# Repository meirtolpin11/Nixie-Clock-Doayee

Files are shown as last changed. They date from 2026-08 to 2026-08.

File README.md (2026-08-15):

# Nixie Clock Driver (Doayee IN-12B)

A 6-digit IN-12B Nixie tube display and driver board designed in KiCad.

Schematic Preview

---

## Overview

This project is a modular Nixie tube driver board tailored for Russian **IN-12B** cold-cathode neon display tubes. It utilizes the **HV5122PG** high-voltage 32-channel shift register IC to drive tube cathodes with minimal microcontroller I/O pins, paired with individually driven RGB backlights underneath each tube.

### Key Features
* **6x IN-12B Nixie Tube Sockets**: DSUB-style footprint mounting with decimal point support.
* **Microchip/Supertex HV5122PG High-Voltage Driver**: 32 high-voltage open-drain outputs with internal shift register and latch.
* **RGB Tube Backlighting**: Dedicated Cree PLCC4 / SMD RGB LEDs for under-glow effects.
* **Integrated Logic**: 74LVC1G79 D-type flip-flop for high-speed clock/data synchronization.
* **Self-Contained Library Management**: All custom symbols, footprints, and 3D models are bundled in the repository and mapped via relative project variables (`${KIPRJMOD}`).

---

## Repository Structure

```
├── Nixie.kicad_pro              # KiCad project file
├── Nixie.kicad_sch              # Main schematic
├── Nixie.kicad_pcb              # PCB layout
├── sym-lib-table                # Project symbol library table (portable ${KIPRJMOD})
├── fp-lib-table                 # Project footprint library table (portable ${KIPRJMOD})
├── libs/                        # Bundled component libraries
│   ├── symbols/                 # Symbol libraries (.kicad_sym)
│   │   ├── HV5122_Doayee.kicad_sym
│   │   ├── HV5122PG-G.kicad_sym
│   │   ├── 74LVC1G79GW-Q100H.kicad_sym
│   │   ├── nixies-us.kicad_sym
│   │   ├── mynixies.kicad_sym
│   │   ├── nixiemisc.kicad_sym
│   │   └── CustomComponents.kicad_sym
│   ├── footprints/              # Footprint libraries (.pretty folders)
│   │   ├── HV5122PG-G.pretty/
│   │   ├── 74LVC1G79GW.pretty/
│   │   ├── nixies-us.pretty/
│   │   ├── mynixies.pretty/
│   │   ├── nixiemisc.pretty/
│   │   └── CustomComponents.pretty/
│   └── 3dmodels/                # 3D models (.wrl / .step)
│       └── IN-12B.wrl, box_header_*.wrl
├── datasheets/                  # Component datasheets (IN-12B, HV5122, etc.)
├── production/                  # Manufacturing outputs
│   └── gerbers/                 # Gerbers and drill files
├── docs/                        # Exported documentation
│   ├── schematic.pdf            # Schematic in PDF format
│   └── pcb_top.svg              # Top-layer SVG rendering
└── archive/                     # Historical KiCad 4/5 files
    └── legacy_kicad4/
```

---

## How to Open in KiCad

1. Clone this repository:
   ```bash
   git clone git@github.com:meirtolpin11/Nixie-Clock-Doayee.git
   ```
2. Open **KiCad** (version 7, 8, 9, or 10).
3. Select **File -> Open Project...** and select `Nixie.kicad_pro`.
4. All symbols and footprints are pre-configured to resolve automatically using `${KIPRJMOD}`—no manual library configuration is needed.

---

## Documentation & Exports

* **Schematic PDF**: [docs/schematic.pdf](docs/schematic.pdf)
* **Gerber Files**: [production/gerbers/](production/gerbers/)
* **Datasheets**: [datasheets/](datasheets/)

---

## License

Hardware design and files are provided for personal and open-source hobbyist use.

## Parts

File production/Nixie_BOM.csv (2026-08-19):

Refs | Value | Footprint | Qty | DNP
C6 | 100nF | Capacitor_THT:C_Disc_D4.7mm_W2.5mm_P5.00mm | 1
C7 | 100nF | Capacitor_THT:C_Disc_D4.7mm_W2.5mm_P5.00mm | 1
C8 | 10nF | Capacitor_THT:C_Disc_D4.7mm_W2.5mm_P5.00mm | 1
C9 | 10nF | Capacitor_THT:C_Disc_D4.7mm_W2.5mm_P5.00mm | 1
D1 | Led_RGB_CA | LED_SMD:LED_Cree-PLCC4_5x5mm_CW | 1
D2 | Led_RGB_CA | LED_SMD:LED_Cree-PLCC4_5x5mm_CW | 1
D3 | Led_RGB_CA | LED_SMD:LED_Cree-PLCC4_5x5mm_CW | 1
D4 | Led_RGB_CA | LED_SMD:LED_Cree-PLCC4_5x5mm_CW | 1
D5 | LED | LED_THT:LED_D3.0mm | 1
D6 | Led_RGB_CA | LED_SMD:LED_Cree-PLCC4_5x5mm_CW | 1
D7 | Led_RGB_CA | LED_SMD:LED_Cree-PLCC4_5x5mm_CW | 1
J1 | Led output | Connector_PinHeader_2.54mm:PinHeader_1x18_P2.54mm_Vertical | 1
J2 | Led Input | Connector_PinHeader_2.54mm:PinHeader_1x18_P2.54mm_Vertical | 1
J3 | Conn_01x03 | Connector_PinHeader_2.54mm:PinHeader_1x03_P2.54mm_Vertical | 1
JP1 | M10LOCK | Connector_PinHeader_2.54mm:PinHeader_1x07_P2.54mm_Vertical | 1
N1 | IN-12B | nixies-us:nixies-us-IN-12-DSUB-NOHOLE | 1
N2 | IN-12B | nixies-us:nixies-us-IN-12-DSUB-NOHOLE | 1
N3 | IN-12B | nixies-us:nixies-us-IN-12-DSUB-NOHOLE | 1
N4 | IN-12B | nixies-us:nixies-us-IN-12-DSUB-NOHOLE | 1
N5 | IN-12B | nixies-us:nixies-us-IN-12-DSUB-NOHOLE | 1
N6 | IN-12B | nixies-us:nixies-us-IN-12-DSUB-NOHOLE | 1
Q1 | Q_NMOS_GSD | Package_TO_SOT_SMD:SOT-23 | 1
R1 | 100R | Resistor_THT:R_Axial_DIN0207_L6.3mm_D2.5mm_P7.62mm_Horizontal | 1
R2 | 120R | Resistor_THT:R_Axial_DIN0207_L6.3mm_D2.5mm_P7.62mm_Horizontal | 1
R3 | 120R | Resistor_THT:R_Axial_DIN0207_L6.3mm_D2.5mm_P7.62mm_Horizontal | 1
R4 | 1K5 | Resistor_THT:R_Axial_DIN0207_L6.3mm_D2.5mm_P7.62mm_Horizontal | 1
R5 | 1K5 | Resistor_THT:R_Axial_DIN0207_L6.3mm_D2.5mm_P7.62mm_Horizontal | 1
R6 | 1K5 | Resistor_THT:R_Axial_DIN0207_L6.3mm_D2.5mm_P7.62mm_Horizontal | 1
R7 | 1K5 | Resistor_THT:R_Axial_DIN0207_L6.3mm_D2.5mm_P7.62mm_Horizontal | 1
R8 | 1K5 | Resistor_THT:R_Axial_DIN0207_L6.3mm_D2.5mm_P7.62mm_Horizontal | 1
R9 | 1K5 | Resistor_THT:R_Axial_DIN0207_L6.3mm_D2.5mm_P7.62mm_Horizontal | 1
R10 | 100R | Resistor_THT:R_Axial_DIN0207_L6.3mm_D2.5mm_P7.62mm_Horizontal | 1
R11 | 120R | Resistor_THT:R_Axial_DIN0207_L6.3mm_D2.5mm_P7.62mm_Horizontal | 1
R12 | 120R | Resistor_THT:R_Axial_DIN0207_L6.3mm_D2.5mm_P7.62mm_Horizontal | 1
R13 | 100R | Resistor_THT:R_Axial_DIN0207_L6.3mm_D2.5mm_P7.62mm_Horizontal | 1
R14 | 120R | Resistor_THT:R_Axial_DIN0207_L6.3mm_D2.5mm_P7.62mm_Horizontal | 1
R15 | 120R | Resistor_THT:R_Axial_DIN0207_L6.3mm_D2.5mm_P7.62mm_Horizontal | 1
R16 | 100R | Resistor_THT:R_Axial_DIN0207_L6.3mm_D2.5mm_P7.62mm_Horizontal | 1
R17 | 120R | Resistor_THT:R_Axial_DIN0207_L6.3mm_D2.5mm_P7.62mm_Horizontal | 1
R18 | 120R | Resistor_THT:R_Axial_DIN0207_L6.3mm_D2.5mm_P7.62mm_Horizontal | 1
R19 | 120R | Resistor_THT:R_Axial_DIN0207_L6.3mm_D2.5mm_P7.62mm_Horizontal | 1
R20 | 100R | Resistor_THT:R_Axial_DIN0207_L6.3mm_D2.5mm_P7.62mm_Horizontal | 1
R21 | 120R | Resistor_THT:R_Axial_DIN0207_L6.3mm_D2.5mm_P7.62mm_Horizontal | 1
R22 | 120R | Resistor_THT:R_Axial_DIN0207_L6.3mm_D2.5mm_P7.62mm_Horizontal | 1
R23 | 100R | Resistor_THT:R_Axial_DIN0207_L6.3mm_D2.5mm_P7.62mm_Horizontal | 1
R24 | 120R | Resistor_THT:R_Axial_DIN0207_L6.3mm_D2.5mm_P7.62mm_Horizontal | 1
R25 | 120R | Resistor_THT:R_Axial_DIN0207_L6.3mm_D2.5mm_P7.62mm_Horizontal | 1
R26 | 10K | Resistor_THT:R_Axial_DIN0207_L6.3mm_D2.5mm_P7.62mm_Horizontal | 1
R27 | 10K | Resistor_THT:R_Axial_DIN0207_L6.3mm_D2.5mm_P7.62mm_Horizontal | 1
U1 | 74LVC1G79 | Package_TO_SOT_SMD:SOT-23-5_HandSoldering | 1
U2 | HV5122 | HV5122PG-G:QFP80P1390X1390X235-44N | 1
U3 | HV5122 | HV5122PG-G:QFP80P1390X1390X235-44N | 1

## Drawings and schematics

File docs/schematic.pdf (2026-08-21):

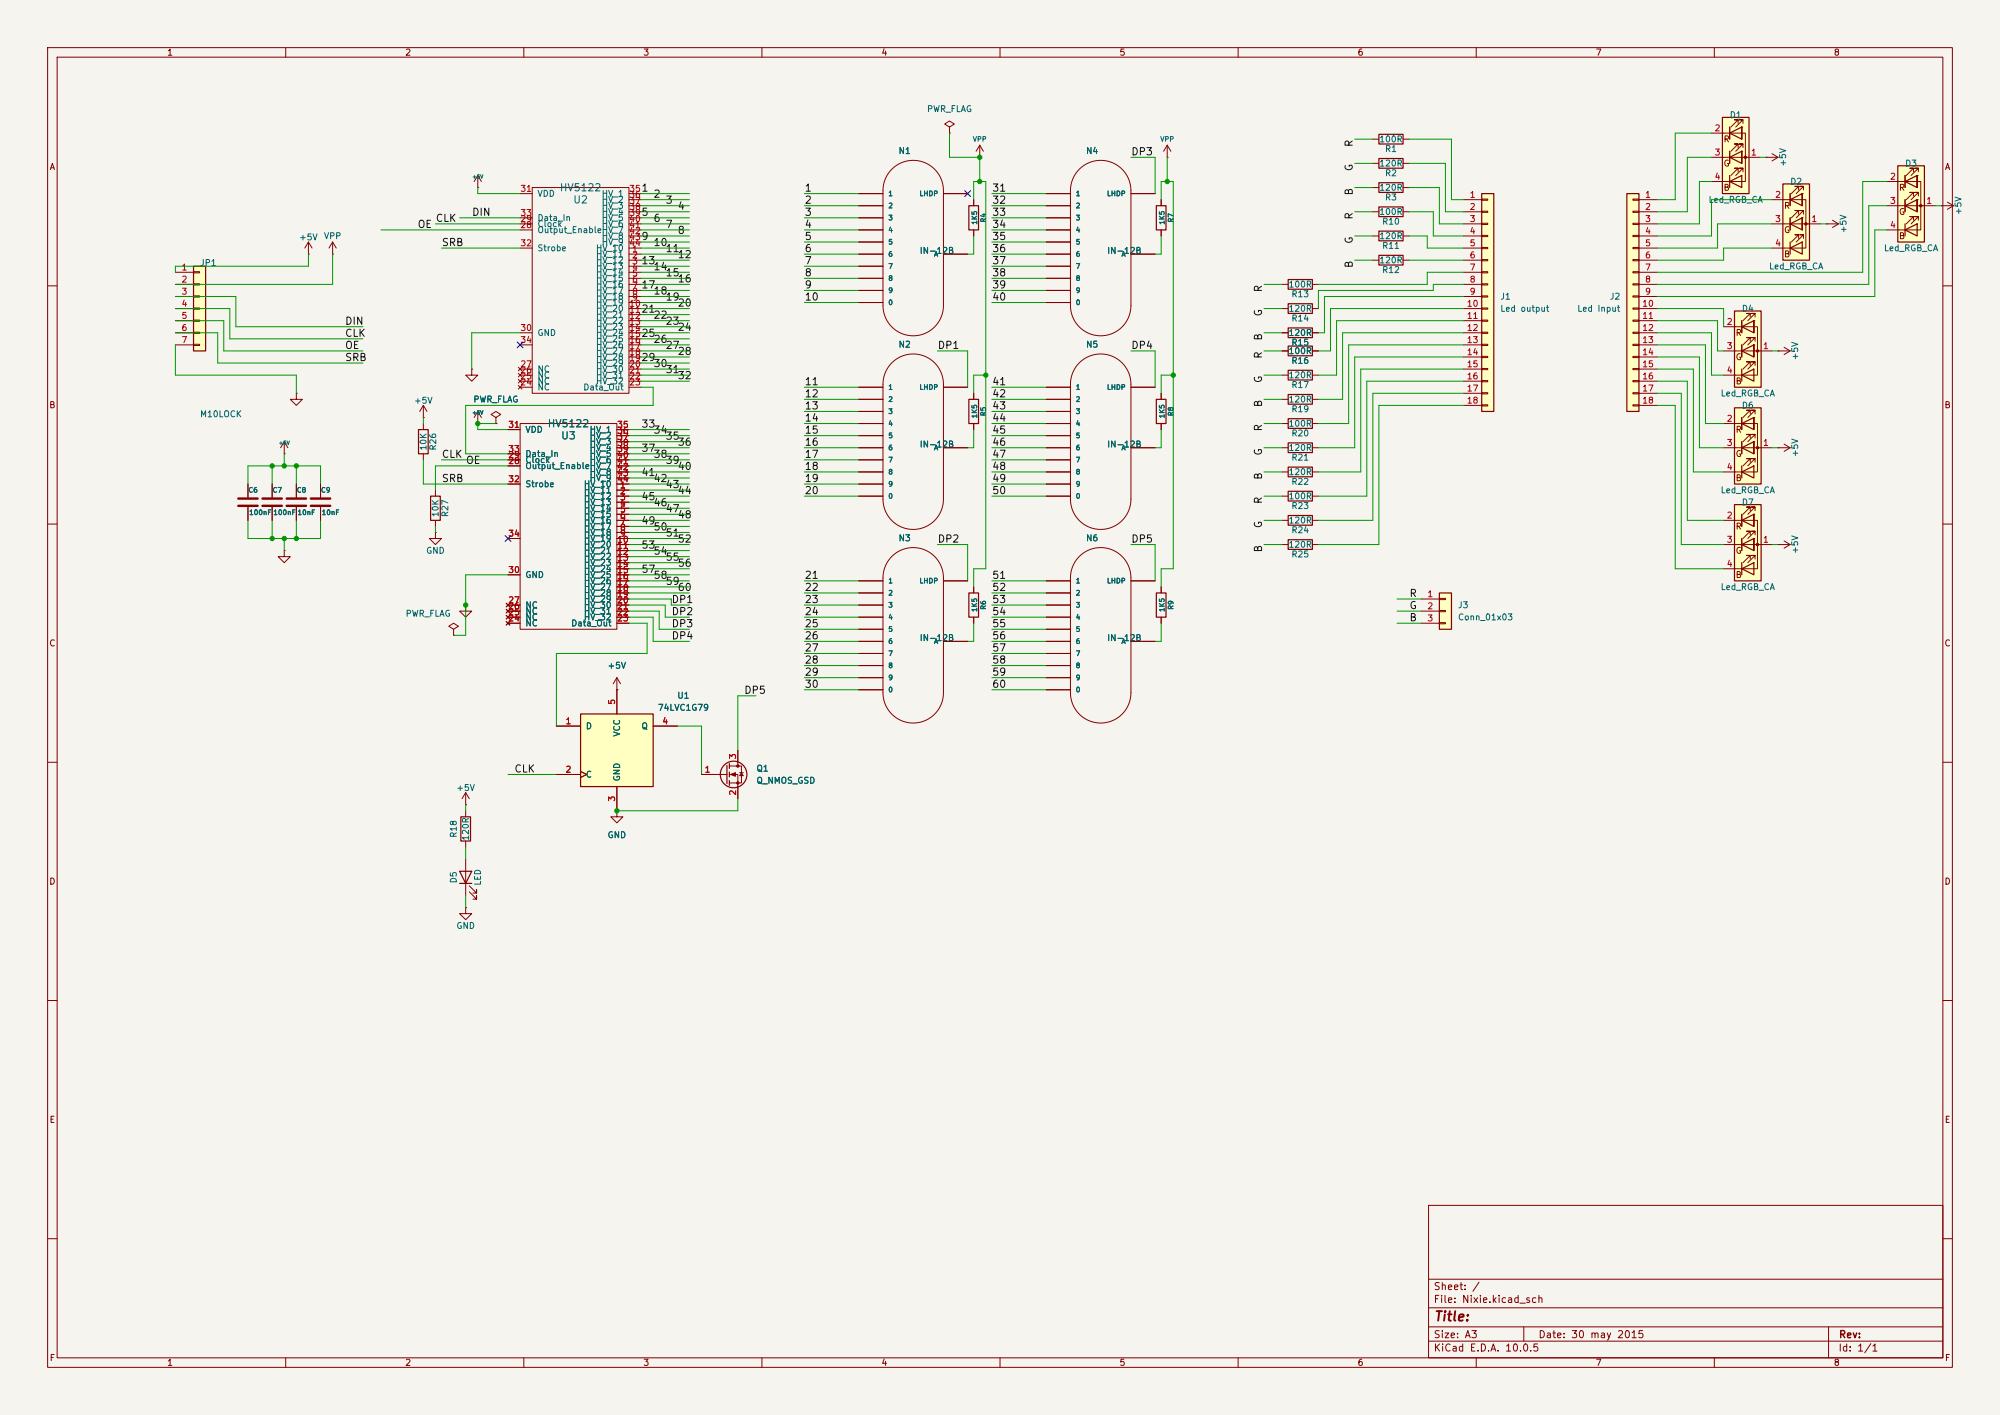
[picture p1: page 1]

Size: A3 | Rev: | F Date: 30 may 2015
KiCad E.D.A. 10.0.5 | Id: 1/1

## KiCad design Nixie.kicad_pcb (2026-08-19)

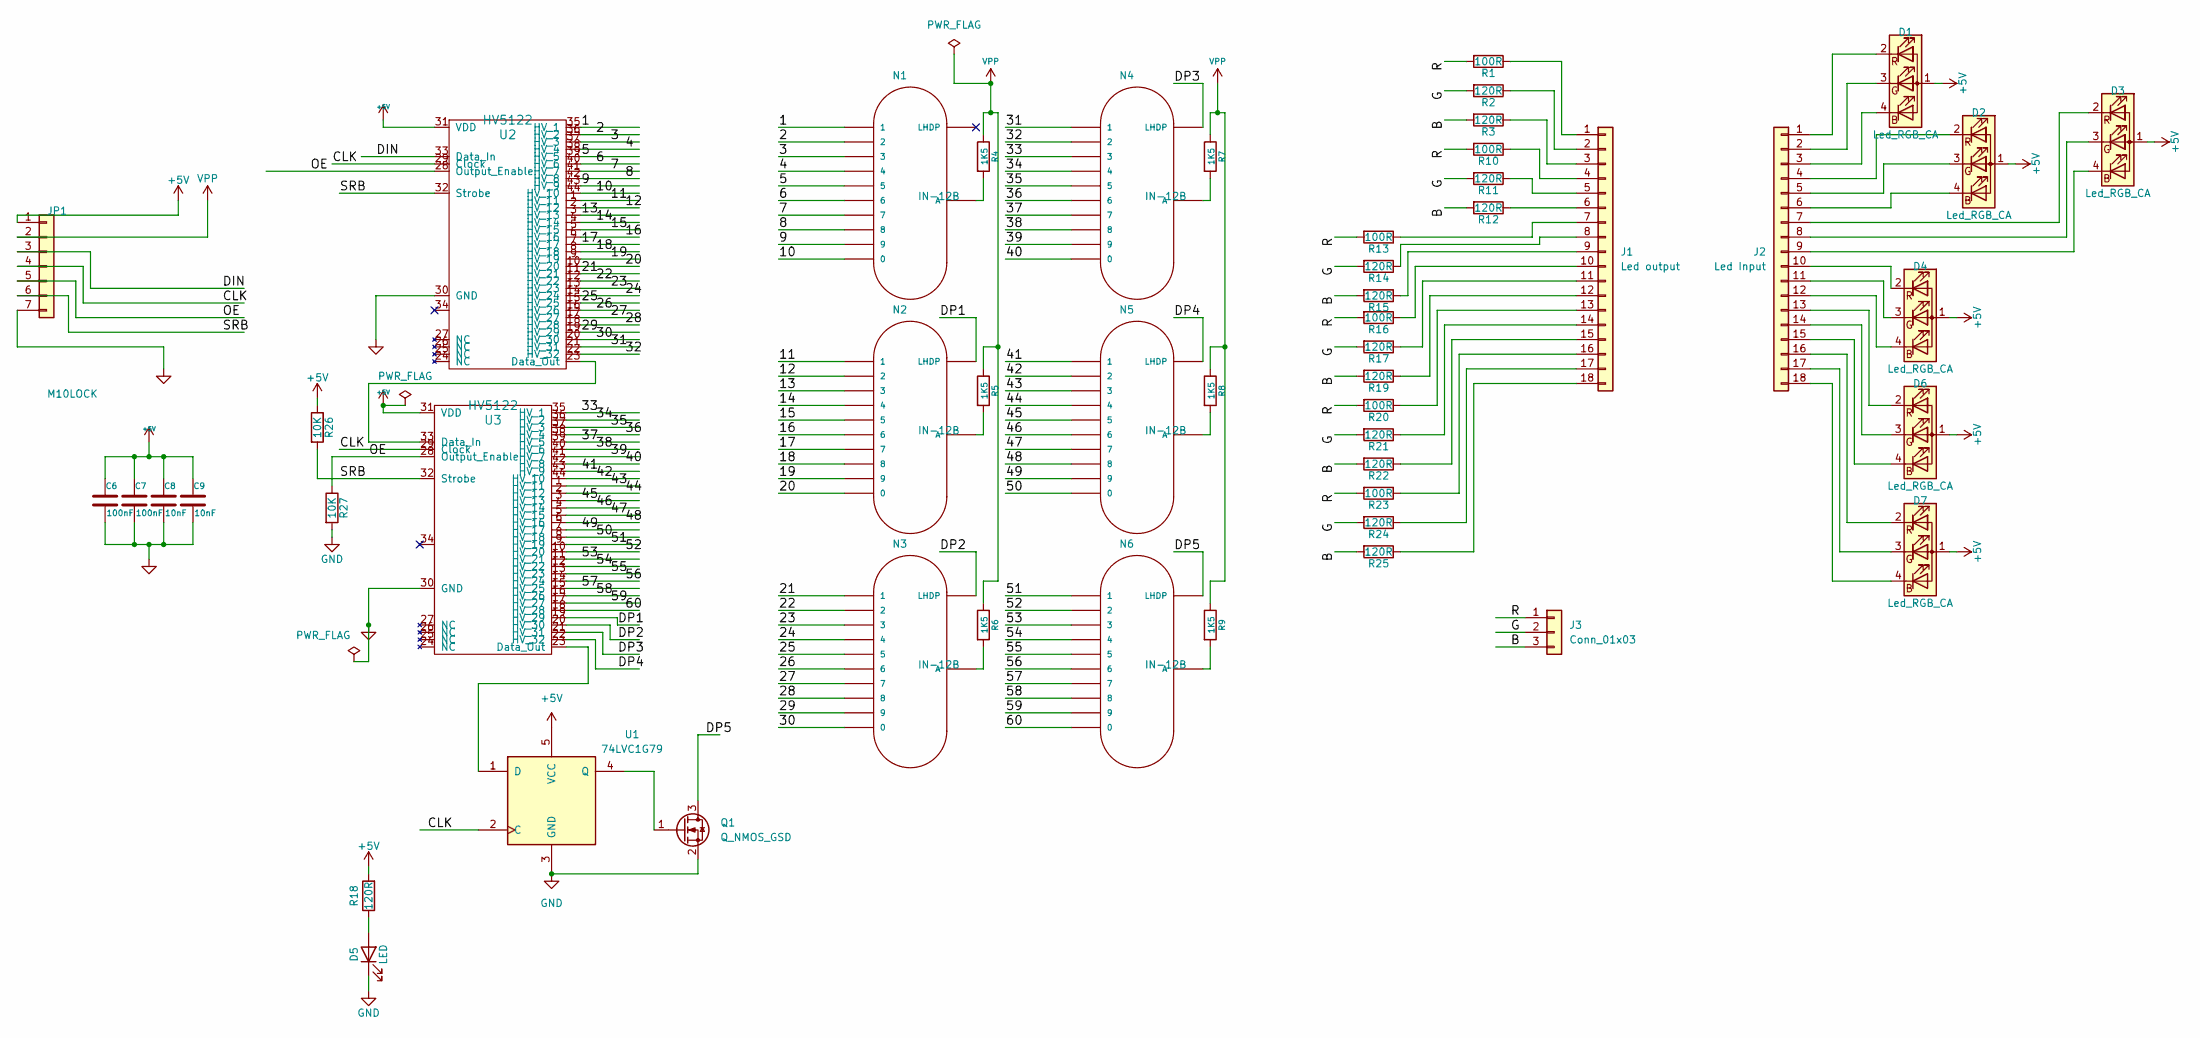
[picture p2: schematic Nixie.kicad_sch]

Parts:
C6, C7: 100nF; C_Disc_D3.0mm_W2.0mm_P2.50mm
C8, C9: 10nF; C_Disc_D3.0mm_W2.0mm_P2.50mm
D1, D2, D3, D4, D6, D7: Led_RGB_CA; LED_Cree-PLCC4_5x5mm_CW
D5: LED; LED_D3.0mm
J1: Led output; PinHeader_1x20_P1.00mm_Vertical
J2: Led Input; PinHeader_1x20_P1.00mm_Vertical
J3: Conn_01x03; PinHeader_1x03_P1.00mm_Vertical
JP1: M10LOCK; PinHeader_1x10_P1.00mm_Vertical
N1, N2, N3, N4, N5, N6: IN-12B; nixies-us-IN-12-DSUB-NOHOLE
Q1: Q_NMOS_GSD; SOT-23
R1, R10, R13, R16, R20, R23: 100R; R_Axial_DIN0207_L6.3mm_D2.5mm_P7.62mm_Horizontal
R2, R3, R11, R12, R14, R15, R17, R18, R19, R21, R22, R24, R25: 120R; R_Axial_DIN0207_L6.3mm_D2.5mm_P7.62mm_Horizontal
R4, R5, R6, R7, R8, R9: 1K5; R_Axial_DIN0207_L6.3mm_D2.5mm_P7.62mm_Horizontal
R26, R27: 10K; R_Axial_DIN0207_L6.3mm_D2.5mm_P7.62mm_Horizontal
U1: 74LVC1G79; SOT-23-5_HandSoldering
U2, U3: HV5122; QFP80P1390X1390X235-44N

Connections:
+5V: C6.1, C7.1, C8.1, C9.1, D1.1 (A), D2.1 (A), D3.1 (A), D4.1 (A), D6.1 (A), D7.1 (A), JP1.1, R18.2, R26.1, U1.5 (VCC), U2.31 (VDD), U3.31 (VDD)
/1: N1.1, U2.35 (HV_1)
/2: N1.2, U2.36 (HV_2)
/3: N1.3, U2.37 (HV_3)
/4: N1.4, U2.38 (HV_4)
/5: N1.5, U2.39 (HV_5)
/6: N1.6, U2.40 (HV_6)
/7: N1.7, U2.41 (HV_7)
/8: N1.8, U2.42 (HV_8)
/9: N1.9, U2.43 (HV_9)
/10: N1.0, U2.44 (HV_10)
/11: N2.1, U2.1 (HV_11)
/12: N2.2, U2.2 (HV_12)
/13: N2.3, U2.3 (HV_13)
/14: N2.4, U2.4 (HV_14)
/15: N2.5, U2.5 (HV_15)
/16: N2.6, U2.6 (HV_16)
/17: N2.7, U2.7 (HV_17)
/18: N2.8, U2.8 (HV_18)
/19: N2.9, U2.9 (HV_19)
/20: N2.0, U2.10 (HV_20)
/21: N3.1, U2.11 (HV_21)
/22: N3.2, U2.12 (HV_22)
/23: N3.3, U2.13 (HV_23)
/24: N3.4, U2.14 (HV_24)
/25: N3.5, U2.15 (HV_25)
/26: N3.6, U2.16 (HV_26)
/27: N3.7, U2.17 (HV_27)
/28: N3.8, U2.18 (HV_28)
/29: N3.9, U2.19 (HV_29)
/30: N3.0, U2.20 (HV_30)
/31: N4.1, U2.21 (HV_31)
/32: N4.2, U2.22 (HV_32)
/33: N4.3, U3.35 (HV_1)
/34: N4.4, U3.36 (HV_2)
/35: N4.5, U3.37 (HV_3)
/36: N4.6, U3.38 (HV_4)
/37: N4.7, U3.39 (HV_5)
/38: N4.8, U3.40 (HV_6)
/39: N4.9, U3.41 (HV_7)
/40: N4.0, U3.42 (HV_8)
/41: N5.1, U3.43 (HV_9)
/42: N5.2, U3.44 (HV_10)
/43: N5.3, U3.1 (HV_11)
/44: N5.4, U3.2 (HV_12)
/45: N5.5, U3.3 (HV_13)
/46: N5.6, U3.4 (HV_14)
/47: N5.7, U3.5 (HV_15)
/48: N5.8, U3.6 (HV_16)
/49: N5.9, U3.7 (HV_17)
/50: N5.0, U3.8 (HV_18)
/51: N6.1, U3.9 (HV_19)
/52: N6.2, U3.10 (HV_20)
/53: N6.3, U3.11 (HV_21)
/54: N6.4, U3.12 (HV_22)
/55: N6.5, U3.13 (HV_23)
/56: N6.6, U3.14 (HV_24)
/57: N6.7, U3.15 (HV_25)
/58: N6.8, U3.16 (HV_26)
/59: N6.9, U3.17 (HV_27)
/60: N6.0, U3.18 (HV_28)
/B: J3.3, R3.2, R12.2, R15.2, R19.2, R22.2, R25.2
/CLK: JP1.4, U1.2 (C), U2.29 (Clock), U3.29 (Clock)
/DIN: JP1.3, U2.33 (Data_In)
/DP1: N2.LHDP, U3.19 (HV_29)
/DP2: N3.LHDP, U3.20 (HV_30)
/DP3: N4.LHDP, U3.21 (HV_31)
/DP4: N5.LHDP, U3.22 (HV_32)
/DP5: N6.LHDP, Q1.3 (D)
/G: J3.2, R2.2, R11.2, R14.2, R17.2, R21.2, R24.2
/OE: JP1.5, R27.1, U2.28 (Output_Enable), U3.28 (Output_Enable)
/R: J3.1, R1.2, R10.2, R13.2, R16.2, R20.2, R23.2
/SRB: JP1.6, R26.2, U2.32 (Strobe), U3.32 (Strobe)
GND: C6.2, C7.2, C8.2, C9.2, D5.1 (K), JP1.7, Q1.2 (S), R27.2, U1.3 (GND), U2.30 (GND), U3.30 (GND)
unnamed: D1.4 (BK), J2.3
unnamed: D1.3 (GK), J2.2
unnamed: D1.2 (RK), J2.1
unnamed: D2.4 (BK), J2.6
unnamed: D2.3 (GK), J2.5
unnamed: D2.2 (RK), J2.4
unnamed: D3.4 (BK), J2.9
unnamed: D3.3 (GK), J2.8
unnamed: D3.2 (RK), J2.7
unnamed: D4.4 (BK), J2.12
unnamed: D4.3 (GK), J2.11
unnamed: D4.2 (RK), J2.10
unnamed: D5.2 (A), R18.1
unnamed: D6.4 (BK), J2.15
unnamed: D6.3 (GK), J2.14
unnamed: D6.2 (RK), J2.13
unnamed: D7.4 (BK), J2.18
unnamed: D7.3 (GK), J2.17
unnamed: D7.2 (RK), J2.16
unnamed: J1.1, R1.1
unnamed: J1.2, R2.1
unnamed: J1.3, R3.1
unnamed: J1.4, R10.1
unnamed: J1.5, R11.1
unnamed: J1.6, R12.1
unnamed: J1.7, R13.1
unnamed: J1.8, R14.1
unnamed: J1.9, R15.1
unnamed: J1.10, R16.1
unnamed: J1.11, R17.1
unnamed: J1.12, R19.1
unnamed: J1.13, R20.1
unnamed: J1.14, R21.1
unnamed: J1.15, R22.1
unnamed: J1.16, R23.1
unnamed: J1.17, R24.1
unnamed: J1.18, R25.1
unnamed: N1.A, R4.2
unnamed: N2.A, R5.2
unnamed: N3.A, R6.2
unnamed: N4.A, R7.2
unnamed: N5.A, R8.2
unnamed: N6.A, R9.2
unnamed: Q1.1 (G), U1.4 (Q)
unnamed: U1.1 (D), U3.23 (Data_Out)
unnamed: U2.23 (Data_Out), U3.33 (Data_In)
VPP: JP1.2, R4.1, R5.1, R6.1, R7.1, R8.1, R9.1

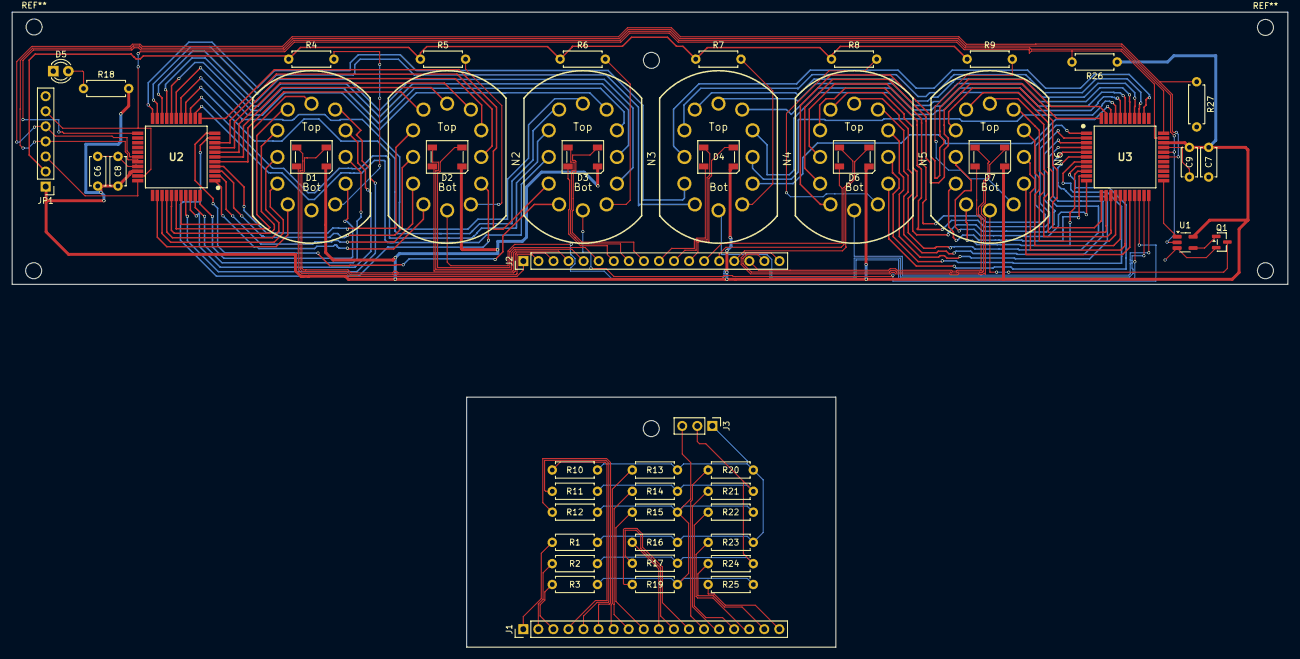
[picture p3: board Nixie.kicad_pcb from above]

Board: 2 copper layers, 215.1 x 107.1 mm, 52 parts (0 on the bottom side), 121 nets.

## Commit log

2026-08-15 Initial commit: Restructure KiCad Nixie project with self-contained libraries and documentation
    [Nixie-B.Cu.gbr, Nixie-B.Mask.gbr, Nixie-B.SilkS.gbr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]
2026-08-15 Update PCB layout, schematic, and documentation exports
    [Nixie.kicad_pcb, Nixie.kicad_sch]
2026-08-16 Update PCB layout, schematic exports, design rules, and manufacturing gerbers
    [Nixie-B.Cu.gbr, Nixie-B.Mask.gbr, Nixie-B.SilkS.gbr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]
2026-08-16 Update PCB layout, design rules, SVG/PDF exports, and gerbers
    [Nixie-B_Cu.gbr, Nixie-B_Mask.gbr, Nixie-B_Silkscreen.gbr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]
2026-08-17 Update PCB layout, SVG/PDF exports, and gerber manufacturing files
    [Nixie-B_Cu.gbr, Nixie-B_Mask.gbr, Nixie-B_Silkscreen.gbr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]
2026-08-19 Update schematic connector JP1, PCB routing, BOM, and export files
    [Nixie-B_Cu.gbr, Nixie-B_Mask.gbr, Nixie-B_Silkscreen.gbr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]
2026-08-19 Update PCB mounting hole positions, layout routing, SVG export, and gerbers
    [Nixie-B_Cu.gbr, Nixie-B_Mask.gbr, Nixie-B_Silkscreen.gbr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]
2026-08-19 Update schematic and export latest schematic PDF
    [Nixie.kicad_sch]
2026-08-19 Update BOM CSV with 2.54mm headers and 5.00mm capacitor footprints
    [Nixie.csv]
2026-08-21 Export updated production deliverables: Gerbers ZIP, CPL, BOM, schematic PDF and SVG
    [Nixie-B_Cu.gbr, Nixie-B_Mask.gbr, Nixie-B_Silkscreen.gbr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]
